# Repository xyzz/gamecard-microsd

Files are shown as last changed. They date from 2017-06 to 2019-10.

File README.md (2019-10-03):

# PS Vita gamecard to microSD adapter

## Software

`driver` contains a kernel module. Add it to taihen's `config.txt` KERNEL section. You can download a precompiled `.skprx` from the [Releases](https://github.com/xyzz/gamecard-microsd/releases) section.

Your microSD card must have no partition table. exFAT filesystem should be written directly to the device. On Linux, do:

```
mkfs.exfat /dev/sdx # (without a number)
```

On Windows, this works: https://redd.it/6o4gqh / https://redd.it/6o62vx

On Mac this should work (Tested on OSX 10.12):

```
# List your attached storage, find your sd card
sudo DiskUtil list
# If necessary, unmount volume
sudo diskutil unmountdisk /dev/diskn (where n is the number of the mounted sd card)
# Format drive
sudo newfs_exfat -R /dev/diskn  
```

After that, the card still works on both Linux and Windows, however other devices might have some problems.

### Compiling the driver

To compile:

```
cd driver
mkdir build && cd build
cmake ..
make
```

## Hardware

`board` contains Autodesk EAGLE schematics and board files. **Note: last revision still untested.**

The pcb has to be 1mm thick. This means I only tested 1mm thick PCBs and found them to work fine. I don't know if other thicknesses work.

Note how the pcb has a hole in place of microsd socket. You need to flip the socket and mount it into the hole .



The socket should look like that. You can buy these from aliexpress for about $0.1-0.2/piece. Check out [issue 2](https://github.com/xyzz/gamecard-microsd/issues/2) for a buying guide.

There's no case for the adapter. Make sure to cover testpoints with some tape to prevent shorts. (v3.0 of the design has no test pads so you do not have to insulate anything). You also will have to use tweezers to remove adapter from PS Vita. Don't grab the adapter by the socket or you risk damaging it.

The adapter does not use Vita gamecard push-pull mechanism. If you feel a spring while inserting it, this means you are inserting it wrong.

If you accidentally short contacts, the Vita will power off. However, in my testing, this does not seem to cause any permanent damage.

Once you insert the adapter, you can replace microSD without taking the adapter out.

## Version history

### v3.0

* Reduced gamecard pads total width by 0.2mm.
* Removed testpads.
* Removed unused INS pad on the microSD socket side.
* Changed routing to reduce number of VIAs and the probability of electrons falling out of the board.

This design is not tested yet.

### v2.0

* Reduced gamecard pads total width by 1.0mm.
* Removed fourth microsd socket leg.

This design is not tested by me yet, but other people confirmed it works.

### v1.0

Original design.

## Alternative designs

You can find some alternative designs here:

* https://github.com/Gadorach/SD2VITA
* https://www.elotrolado.net/hilo_proyecto-hardmod-para-poner-un-lector-de-micro-sd-en-la-psvita_2229693 (Spanish)

(Send a pr if you want to be included here)

## License

Code inside the `driver` directory is licensed under GPLv3 or later.

Contents of the `board` directory are licensed under [CC0](https://creativecommons.org/publicdomain/zero/1.0/).

## Special thanks to

* @motoharu-gosuto for their work on gamecard RE
* @TheOfficialFlow for providing original version of the usbmc plugin

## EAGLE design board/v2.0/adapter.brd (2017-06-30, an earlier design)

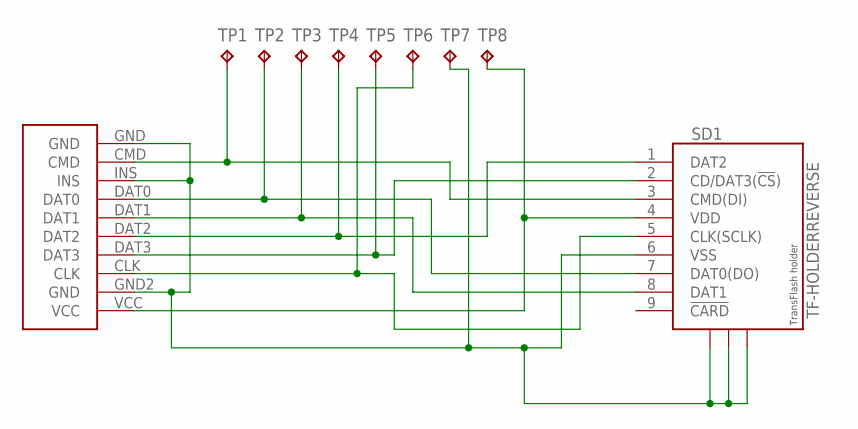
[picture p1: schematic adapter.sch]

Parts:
SD1: TF-HOLDERREVERSE; TF-PULL-REVERSE
TP1, TP2, TP3, TP4, TP5, TP6, TP7, TP8: TPTP20R; TP20R
U$1: CONNECTOR

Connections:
GND: SD1.6 (VSS), SD1.S1, SD1.S2, SD1.S3, TP7.TP, U$1.GND, U$1.GND2 (GND), U$1.INS
unnamed: SD1.4 (VDD), TP8.TP, U$1.VCC
unnamed: SD1.3 (CMD(DI)), TP1.TP, U$1.CMD
unnamed: SD1.7 (DAT0(DO)), TP2.TP, U$1.DAT0
unnamed: SD1.8 (DAT1), TP3.TP, U$1.DAT1
unnamed: SD1.1 (DAT2), TP4.TP, U$1.DAT2
unnamed: SD1.2 (CD/DAT3(!CS!)), TP5.TP, U$1.DAT3
unnamed: SD1.5 (CLK(SCLK)), TP6.TP, U$1.CLK

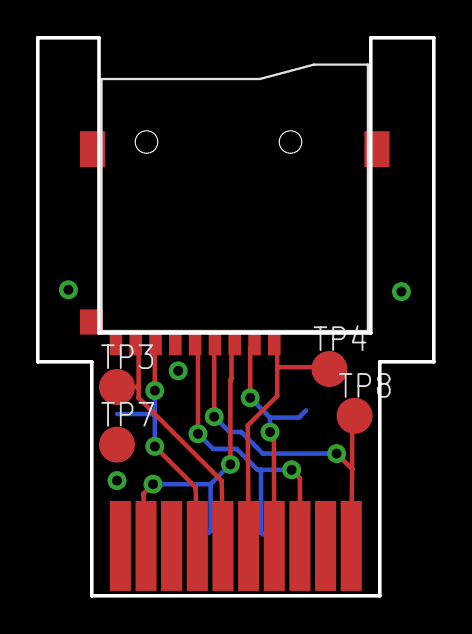
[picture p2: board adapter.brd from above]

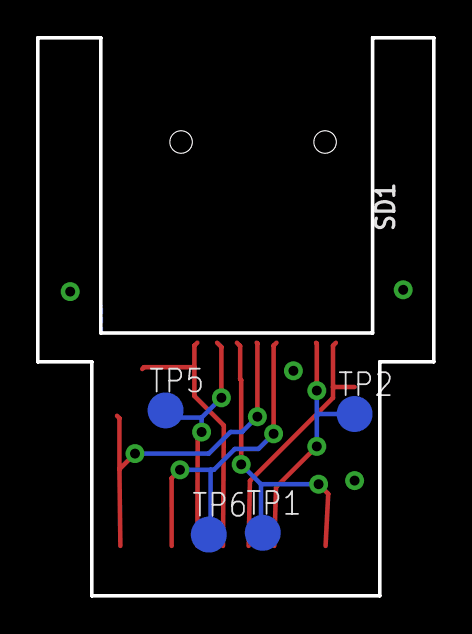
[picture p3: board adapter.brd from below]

Board: 2 copper layers, 22.0 x 31.0 mm, 10 parts (4 on the bottom side), 8 nets.

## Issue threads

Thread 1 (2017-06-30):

Which coating?

devnoname120, 2017-06-30:
xyz: FR4 proto: 2 layers / 5x5cm (2.2x3.1cm) / 1.0mm / HASL / 1oz / Blue / Protopack ±10
basically all default settings except 1mm

xyzz, 2017-07-01:
anything works, just get the default/cheapest one

Closed 2017-07-01.

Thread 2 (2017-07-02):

Sd Connector

DavisDev, 2017-07-02:
Hello Xyzz!,
What is the sd connector model?
Maybe some "serial number" component?
Greetings.

xyzz, 2017-07-02:
I don't know the model number/name. Here's the purchasing guide though.

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

DavisDev, 2017-07-02:
Thanks for answering!
And thanks for all your hard work!

CrazyMaggot, 2017-07-06:
Good afternoon!
Will this work?
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

https://www.chipdip.ru/product0/8492206932

xyzz, 2017-07-06:
I think it should work.

Closed 2017-07-02.

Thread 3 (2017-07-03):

Gerber format

mikadoryu, 2017-07-03:
I'm trying to send a plaque to try this, but the dealer asks me for the circuit in Gerber format (which I try to create but without success from the eagle)

Could you add this format to github?

xyzz, 2017-07-03:
[adapter5.zip](https://github.com/xyzz/gamecard-microsd/files/1119390/adapter5.zip)

Closed 2017-07-03.

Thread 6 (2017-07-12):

Soldering

CrazyMaggot, 2017-07-12:
Good afternoon!
Tell me, do I need to solder the adapter to the card?

xyzz, 2017-07-12:
Yes

CrazyMaggot, 2017-07-12:
Thnx

12 июл. 2017 г. 11:38 пользователь "xyzz" <notifications@github.com>
написал:

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

Closed 2017-07-12.

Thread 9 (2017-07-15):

Error opening board files in Eagle.

a7mag3ddon, 2017-07-15:
Hi,

When i try and open either of the board design files i get this error..

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

xyzz, 2017-07-15:
I double-checked and it is in fact an EAGLE file, which opens fine, so there must be something wrong on your side.

a7mag3ddon, 2017-07-15:
I just downloaded the trial version of AutoDesk Eagle from here > https://www.autodesk.com/products/eagle/free-download

Version 8.2.2 english

What can you suggest i open the files with instead?

a7mag3ddon, 2017-07-15:
What version of eagle are you using ??

xyzz, 2017-07-15:
I use eagle 8.2.1.

Closed 2017-07-15.

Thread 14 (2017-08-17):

Incorrect free memory reported when formatting a high capacity sd with default cluster size

Shinigati, 2017-08-17:
So i'm not entirely sure if this problem is directly related to the plugin or if it's something more focused on the way the vita handles memory cards so i apologise if it's the latter.

but when i formatted my 256gb micro sd card with the default cluster size my vita would always report incorrect free space while windows and all other devices display it just fine but this only happens if the card was filled up by more than about 100gb of data that was tested, and what's more is after a while if i don't do much the free space it claims is still available starts to quickly disappear.

I have flashed zzblank.img, formatted and copied all the files back over twice and the problem still persisted, but finally after talking with a lot of people trying to figure it out i finally found the solution, the free space will only be 100% accurate if when formatting you choose 32kb cluster instead of the default option which in my case was 256kb.

Shinigati, 2017-08-18:
So just a little update on this but some people have reported that one workaround is to format the sd card as Fat32 using the default cluster size which seems to run fine, i have also managed to get 64kb cluster with exFat working as well while 128kb gave the same issue so there definitely appears to be some compatibility issues i just have no idea why.

CelesteBlue-dev, 2017-09-11:
What is your microSD default cluster size ?

Shinigati, 2017-09-11:
I'm now using 64kb and there is no issue at all, before however i believe windows was defaulting it to 256kb, i also made a post on reddit about it and helped a few people by getting them to format using the correct size.

CelesteBlue-dev, 2020-01-11:
Yes, readme should be updated telling that >64kB clusters don't work, and this issue should be closed.

Shinigati, 2020-01-12:
> Yes, readme should be updated telling that >64kB clusters don't work, and this issue should be closed.

I didn't realise this issue was still open but i'm sure everyone knows by now how to correctly format their sd cards.

Closed 2020-01-12.

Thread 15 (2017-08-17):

SD2Vita/gamesd.skprx constantly waking up device

tiduscrying, 2017-08-17:
I've created a few threads over the past couple of days both on [GBATemp](http://gbatemp.net/threads/investigating-a-potential-bug-with-gamesd-skprx.481123/) and on [/r/vitahacks](https://www.reddit.com/r/vitahacks/comments/6twvat/some_really_weird_behavior_with_my_vita/) trying to isolate the issue. It appears that the gamesd.skprx plugin might be causing an issue where the Vita will wake itself up from sleep mode. On my system, the screen will come on completely, the PS button light will flash and then it will go back to sleep after a few seconds. Normally I wouldn't mind this behavior if it happened only once or twice, but it seems to be happening constantly for me and some others (someone reported losing nearly 50% of their battery over night due to constant wake-ups).

I don't have any absolutely concrete evidence aside from the user accounts and my own personal accounts, but I hope that is enough evidence to justify this bug report.

Here are some additional things that I have done to isolate the issue:

- Disable all Henkaku plugins on boot by hold L - issue did not occur
- Disabled just the gamesd.skprx - issue did not occur
- Tried using different SD2Vita adapters - issue occurred
- Tried reinstalling Enso - issue occurred

Again, hopefully this is enough concrete evidence to justify this bug report. This is the only repo I have found for the gamesd.skprx plugin, but I know multiple "versions" of it are floating around. I would assume though that this is where all the versions of the plugin are coming from since I haven't found any other source code anywhere else.

xyzz, 2017-08-17:
Can you try enabling airplane mode?

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

tiduscrying, 2017-08-17:
That actually seems to be working...? Huh. Is there a specific reason for that?

xyzz, 2017-08-17:
I think what happens is that vita wakes up sometimes to check PSN updates, etc (with the screen turned off.)

However, due to my hook executed in resume which pokes gamecard slot to ensure it's mounted, the whole system wakes up. It probably could be fixed by reversing how the system mounts normal game card on wakeup. I don't have time to do that anytime soon, sadly.

tiduscrying, 2017-08-17:
Interesting! Thank you for the info, I should be keeping my system in sleep mode to save battery and hide from Sony anyways! I'll post this to the threads I made so that others can put their systems into sleep mode and avoid the issue for the time being as well.

Thank you!!

tiduscrying, 2017-08-17:
Edit: Well, it seems that I was not paying attention long enough... Just after posting the information to the threads, someone commented saying that their system has been waking itself up but has been in airplane mode the entire time. Literally just as I was about to reply, I witnessed it happen to my own system as well. So I guess airplane mode doesn't eliminate the issue completely?

xyzz, 2017-08-17:
I see, that's unfortunate. You can test the theory however by disabling `suspend_callback`. If it does not work, then I'm not sure what could cause that. If it does work, that's great, microsd won't be mounted after wakeup so a different way to activate it would be needed (right now it simulates removal and reinsertion of game card).

Duckbuster, 2017-08-23:
>(right now it simulates removal and reinsertion of game card)
Is that why it takes a bit longer to load when you open the lockscreen?
(after you swipe it, there's a loading circle thing for me)

slickrasta, 2017-09-26:
I'm having the same issue on my Vita 1000. Airplane mode doesn't seem to help. How would I go about disabling suspend_callback to test that?

slickrasta, 2017-09-26:
Not sure if this is helpful info I do use VitaBright and NoLED plugins and pretty much solely use my Vita to play PS1 games via Adrenaline v6.

SeraphSephiroth, 2017-12-09:
Any update on a fix for this?

devingDev, 2018-03-17:
Not from xyz , does not seem like he can continue working on this so we have to figure it out ourselves.

xyzz, 2018-07-21:
I've tried fixing the issue, please try the attached build and let me know if your vita still wakes up randomly.

[gamesd.zip](https://github.com/xyzz/gamecard-microsd/files/2215779/gamesd.zip)

xyzz, 2018-07-21:
It seems people are still experiencing the issue so I've made another build with a different fix, try it out.

[gamesd.zip](https://github.com/xyzz/gamecard-microsd/files/2216421/gamesd.zip)

xyzz, 2018-07-21:
Okay, here's the third build for testing

[gamesd.zip](https://github.com/xyzz/gamecard-microsd/files/2216608/gamesd.zip)

JuanD817, 2018-07-23:
At 46 minutes, no wakeups at the moment and led doesn't take time to light up

JuanD817, 2018-07-23:
More than an hour in standby and the wakeup issue seems to be fixed :D, i guess third time is the charm, the only problem i see left is that the led turns on at random but i think thats the vitas issue, not the plugin

JuanD817, 2018-07-23:
@CelesteBlue-dev already tried your latest update a couple of weeks ago, it still has random wakeups every couple of minutes, if it got fixed that would be awesome but for now im sticking with this plugin

I commented more than a week ago about the issue here: https://github.com/CelesteBlue-dev/PSVita-StorageMgr/issues/7

CelesteBlue-dev, 2018-07-23:
@JuanD817 on which FW are you ? Is WIFI enabled ? Do you have enso ?
When you were trying StorageMgr, was the LED blinking often in suspend mode ?
Does the LED blink too in third build ?

JuanD817, 2018-07-23:
-FW 3.68
-Wifi is enabled
-I dont have enso
-yes, just the same as when i didnt have my vita with h-encore
-Yes, it still blinks

JuanD817, 2018-07-23:
They both blink the same in suspend mode, but when i use StorageMgr 2.1 after the blinks the LED stays on and my vita wakes up

JuanD817, 2018-07-24:
No problem, glad i could help

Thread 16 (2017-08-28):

sdcard.skprx driver does not play well with usbmc.skprx

hypergreatthing, 2017-08-28:
long story short, i'd like to load yifan's 3g usb device along side the sd2vita card.
The current driver doesn't seem to play nice.  Whichever i call out in config first wins.
Is there anyway to add support for both at the same time?

CelesteBlue-dev, 2017-08-28:
I am developping a plugin that resolves this issue.
It's working.
I'm going to release it in some days.

DieKatzchen, 2017-10-12:
Any progress on this? I'm interested as well, as long as I can choose mount point (since I obviously can't have them both on ux0).

tokyobusridas, 2018-07-27:
Ever get that one put together xyzz? Thanks for everything

CelesteBlue-dev, 2020-01-11:
Here it is lol:
https://github.com/CelesteBlue-dev/PSVita-StorageMgr

CelesteBlue-dev, 2020-01-11:
> I am developping a plugin that resolves this issue.
> It's working.
> I'm going to release it in some days.

Here it is lol:
https://github.com/CelesteBlue-dev/PSVita-StorageMgr

burtman316, 2020-01-11:
You are amazing thanks!
     On Saturday, January 11, 2020, 7:44:21 AM MST, CelesteBlue-dev <notifications@github.com> wrote:

Here it is lol:
https://github.com/CelesteBlue-dev/PSVita-StorageMgr

—
You are receiving this because you are subscribed to this thread.
Reply to this email directly, view it on GitHub, or unsubscribe.

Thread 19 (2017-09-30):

Use Vita memory and sd2vita together

masoudr, 2017-09-30:
Hi,
Is there a proper way to use vita memory card and sd2vita simultaneously? I mean using apps in memory card and sd2vita.
Thanks.

TheRadziu, 2017-10-02:
there are custom gamesd plugins for that. One mounts memory card to uma0 and sd to ux0, the other does it the other way around. check wololo for links to those.

masoudr, 2017-10-02:
Is this make me use apps in both partitions at the same time or I should reboot each time for accessing apps in these partitions?

TheRadziu, 2017-10-03:
You can move apps between partitions with other homebrew app, but IDK if they will work or not (especially nonpdrm). Homebrew apps do work from another partitions, since I checked it myself.

masoudr, 2017-10-03:
Thanks.
If I understand it right you mean that using sd2vita itself with higher capacity is a better option rather than keep it with vita memory. My concern is performance problems with sd2vita, does it have any negative advantage over original vita memory card?

windsurfer1122, 2017-12-12:
Hi John, there are already pull requests available from August 2017 for this topic.
Would also like to see that xyzz incorporates them into his master branch as v2.0.

I use my SD2Vita as uma0 via an "inoffical" build from [Modshiah](https://www.youtube.com/watch?v=vsdbdcAnH4Y).

masoudr, 2017-12-13:
@windsurfer1122 Thanks. I already test that but the problem is it can only be used for some data types and you cant load the vita games from that directory. I'm waiting for a possibility to use both partitions for my vita games.

windsurfer1122, 2017-12-13:
@masoudr Vita games only work from ux0, that's a firmware issue (AFAIK from the many threads I read).
uma0 works fine for most HomeBrew software including Adrenaline.
I do no see a way how the driver could change the firmware to make Vita games work from uma0.

CelesteBlue-dev, 2020-01-11:
You can try https://github.com/CelesteBlue-dev/PSVita-StorageMgr.

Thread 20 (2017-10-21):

Control over mount points

JohnVeness, 2017-10-21:
Many thanks for the driver code.

As you know, others have modified it to mount the gamecardsd as ux0, and even to mount the genuine Vita memory card as uma0 at the same time.

I _was_ going to ask you if you could make those modifications "official" and have alternative driver binaries available to download from your github page, rather than from random untrusted sites.

But then I wondered whether a single binary driver could read a config file at startup to change its behaviour, i.e. the mount points?

E.g. (and I don't know if this is possible) but maybe "pseudo command line arguments" can be passed via tai/config.txt? Or maybe the driver could read its own config file?

Thank you for reading.

windsurfer1122, 2017-12-12:
Hi John, there are already pull requests available from August 2017 for these topics.
Would also like to see that xyzz incorporates them into his master branch as v2.0

JohnVeness, 2017-12-12:
Ah yes, I hadn't noticed those PRs. In that case, this issue can be closed as dupes of the PRs.

JohnVeness, 2018-03-08:
I haven't tried it but it looks like this idea is implemented in https://github.com/CelesteBlue-dev/PSVita-StorageMgr so I'll close this.

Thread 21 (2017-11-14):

Reverting to Vita MC if no SD card inserted

VgaCich, 2017-11-14:
Mount original Vita MC as ux0: if no SD card inserted.

stuermera, 2018-07-08:
Has this been fixed with the 1.3 release of gamesd? :) Thx

xyzz, 2018-07-08:
No

KupoAuster, 2018-08-02:
Not yet fixed.
And here I was thinking it was a good option.

CelesteBlue-dev, 2018-08-23:
https://github.com/CelesteBlue-dev/PSVita-StorageMgr does that.

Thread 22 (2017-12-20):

Permission Issue? App exits

mazh-dini, 2017-12-20:
Using SD2Vita (without a ps memory card) can cause certain apps not to function properly e.g. moonlight. App constantly returns to game menu when a setting is changed and saved (pressing o when done) or when attempting to type an ip since the configuration files in ux0:data/moonlight are not being created/changed when the app is launched.

Could this be a permission issue of some sort since if I didn't have the SD2Vita then the PS Memory card would be mounted as ux0 and the app would work?

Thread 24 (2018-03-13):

Couple of problems on 3.65

superduperdrew12345, 2018-03-13:
On the newest version compatible with 3.65 enso the memory card is no longer mounted to Uma0. Vitanshell still recognizes it as there and in the previous version it worked as expected. Additionally, I'm having trouble installing nonpdrm games on the sd adapter. When I refresh the livearea it says 0 refreshed but if I move the same files to my sd and then comment out gamesd from config.txt then it installs properly on the memory card. Existing nonpdrm games work still so it seems to be a problem with gamesd not allowing the new folder to be picked up.

xyzz, 2018-03-13:
The memory card was never mounted to uma0 with this plugin. I've no idea about nonpdrm I don't use it, try asking its author.

Closed 2018-03-13.

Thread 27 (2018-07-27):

SD2VITA mounted as uma0 instead (alternate version)

itsminht, 2018-07-27:
Is it possible for each update to this plugin, you also release an alternate version in which the sd2vita card is mounted as uma0 instead of ux0? This would be extremely helpful for the few that use this plugin the other way around.

Avrution, 2018-07-27:
Seconded.  I'd love to have the wakeup fix working, but need to mount as uma0.

xPandamon, 2018-07-27:
Yep, i'm up for that. The sporadic wakeups on storagemgr are super annoying. This one: https://github.com/Ninoh-FOX/gamecard-microsd-uma0/releases doesn't seem to be working properly.

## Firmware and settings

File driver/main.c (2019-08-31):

/*
	gamecard-microsd
	Copyright 2017-2018, xyz

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
	You should have received a copy of the GNU General Public License
	along with this program.  If not, see <http://www.gnu.org/licenses/>.
*/

/*
	This software contains code derived from VitaShell.
	Included below is the license header from VitaShell.
*/

/*
	VitaShell
	Copyright (C) 2015-2017, TheFloW

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
	You should have received a copy of the GNU General Public License
	along with this program.  If not, see <http://www.gnu.org/licenses/>.
*/

#include <psp2kern/kernel/cpu.h>
#include <psp2kern/kernel/modulemgr.h>
#include <psp2kern/kernel/sysmem.h>
#include <psp2kern/io/fcntl.h>
#include <psp2kern/kernel/threadmgr.h>

#include <stdio.h>
#include <string.h>

#include <taihen.h>

#define MOUNT_POINT_ID 0x800

int module_get_offset(SceUID pid, SceUID modid, int segidx, size_t offset, uintptr_t *addr);

typedef struct {
	const char *dev;
	const char *dev2;
	const char *blkdev;
	const char *blkdev2;
	int id;
} SceIoDevice;

typedef struct {
	int id;
	const char *dev_unix;
	int unk;
	int dev_major;
	int dev_minor;
	const char *dev_filesystem;
	int unk2;
	SceIoDevice *dev;
	int unk3;
	SceIoDevice *dev2;
	int unk4;
	int unk5;
	int unk6;
	int unk7;
} SceIoMountPoint;

static SceIoDevice uma_ux0_dev = { "ux0:", "exfatux0", "sdstor0:gcd-lp-ign-entire", "sdstor0:gcd-lp-ign-entire", MOUNT_POINT_ID };

static SceIoMountPoint *(* sceIoFindMountPoint)(int id) = NULL;

static SceIoDevice *ori_dev = NULL, *ori_dev2 = NULL;

static void io_remount(int id) {
	ksceIoUmount(id, 0, 0, 0);
	ksceIoUmount(id, 1, 0, 0);
	ksceIoMount(id, NULL, 0, 0, 0, 0);
}

int shellKernelIsUx0Redirected() {
	SceIoMountPoint *mount = sceIoFindMountPoint(MOUNT_POINT_ID);
	if (!mount) {
		return -1;
	}

	if (mount->dev == &uma_ux0_dev && mount->dev2 == &uma_ux0_dev) {
		return 1;
	}

	return 0;
}

int shellKernelRedirectUx0() {
	SceIoMountPoint *mount = sceIoFindMountPoint(MOUNT_POINT_ID);
	if (!mount) {
		return -1;
	}

	if (mount->dev != &uma_ux0_dev && mount->dev2 != &uma_ux0_dev) {
		ori_dev = mount->dev;
		ori_dev2 = mount->dev2;
	}

	mount->dev = &uma_ux0_dev;
	mount->dev2 = &uma_ux0_dev;

	return 0;
}

int shellKernelUnredirectUx0() {
	SceIoMountPoint *mount = sceIoFindMountPoint(MOUNT_POINT_ID);
	if (!mount) {
		return -1;
	}

	if (ori_dev && ori_dev2) {
		mount->dev = ori_dev;
		mount->dev2 = ori_dev2;

		ori_dev = NULL;
		ori_dev2 = NULL;
	}

	return 0;
}

// ux0 redirect by theflow
int redirect_ux0() {
	// Get tai module info
	tai_module_info_t info;
	info.size = sizeof(tai_module_info_t);
	if (taiGetModuleInfoForKernel(KERNEL_PID, "SceIofilemgr", &info) < 0)
		return -1;

	// Get important function
	switch (info.module_nid) {
		case 0x9642948C: // 3.60 retail
			module_get_offset(KERNEL_PID, info.modid, 0, 0x138C1, (uintptr_t *)&sceIoFindMountPoint);
			break;

		case 0xA96ACE9D: // 3.65 retail
		case 0x3347A95F: // 3.67 retail
		case 0x90DA33DE: // 3.68 retail
			module_get_offset(KERNEL_PID, info.modid, 0, 0x182F5, (uintptr_t *)&sceIoFindMountPoint);
			break;

		case 0xF16E72C7: // 3.69 retail
		case 0x81A49C2B: // 3.70 retail
		case 0xF2D59083: // 3.71 retail
		case 0x9C16D40A: // 3.72 retail
			module_get_offset(KERNEL_PID, info.modid, 0, 0x18735, (uintptr_t *)&sceIoFindMountPoint);
			break;

		default:
			return -1;
	}

	shellKernelRedirectUx0();
	io_remount(MOUNT_POINT_ID);

	return 0;
}

int poke_gamecard() {
	tai_module_info_t info;
	info.size = sizeof(tai_module_info_t);
	if (taiGetModuleInfoForKernel(KERNEL_PID, "SceSdstor", &info) < 0)
		return -1;

	void *args = 0;
	int (*int_insert)() = 0;
	int (*int_remove)() = 0;

	module_get_offset(KERNEL_PID, info.modid, 0, 0x3BD5, (uintptr_t *)&int_insert);
	module_get_offset(KERNEL_PID, info.modid, 0, 0x3BC9, (uintptr_t *)&int_remove);

	module_get_offset(KERNEL_PID, info.modid, 1, 0x1B20 + 40 * 1, (uintptr_t *)&args);

	int_remove(0, args);
	ksceKernelDelayThread(500 * 1000);
	int_insert(0, args);
	ksceKernelDelayThread(500 * 1000);

	return 0;
}

tai_hook_ref_t hook_get_partition;
tai_hook_ref_t hook_write;
tai_hook_ref_t hook_mediaid;

uint32_t magic = 0x7FFFFFFF;

void *sdstor_mediaid;

void *my_get_partition(const char *name, size_t len) {
	void *ret = TAI_CONTINUE(void*, hook_get_partition, name, len);
	if (!ret && len == 18 && strcmp(name, "gcd-lp-act-mediaid") == 0) {
		return &magic;
	}
	return ret;
}

uint32_t my_write(uint8_t *dev, void *buf, uint32_t sector, uint32_t size) {
	if (dev[36] == 1 && sector == magic) {
		return 0;
	}
	return TAI_CONTINUE(uint32_t, hook_write, dev, buf, sector, size);
}

uint32_t my_mediaid(uint8_t *dev) {
	uint32_t ret = TAI_CONTINUE(uint32_t, hook_mediaid, dev);

	if (dev[36] == 1) {
		memset(dev + 20, 0xFF, 16);
		memset(sdstor_mediaid, 0xFF, 16);

		return magic;
	}
	return ret;
}

// allow SD cards, patch by motoharu
void patch_sdstor() {
	tai_module_info_t sdstor_info;
	sdstor_info.size = sizeof(tai_module_info_t);
	if (taiGetModuleInfoForKernel(KERNEL_PID, "SceSdstor", &sdstor_info) < 0)
		return;

	module_get_offset(KERNEL_PID, sdstor_info.modid, 1, 0x1720, (uintptr_t *) &sdstor_mediaid);

	// patch for proc_initialize_generic_2 - so that sd card type is not ignored
	char zeroCallOnePatch[4] = {0x01, 0x20, 0x00, 0xBF};
	taiInjectDataForKernel(KERNEL_PID, sdstor_info.modid, 0, 0x2498, zeroCallOnePatch, 4); //patch (BLX) to (MOVS R0, #1 ; NOP)
	taiInjectDataForKernel(KERNEL_PID, sdstor_info.modid, 0, 0x2940, zeroCallOnePatch, 4);

	taiHookFunctionOffsetForKernel(KERNEL_PID, &hook_get_partition, sdstor_info.modid, 0, 0x142C, 1, my_get_partition);
	taiHookFunctionOffsetForKernel(KERNEL_PID, &hook_write, sdstor_info.modid, 0, 0x2C58, 1, my_write);
	taiHookFunctionOffsetForKernel(KERNEL_PID, &hook_mediaid, sdstor_info.modid, 0, 0x3D54, 1, my_mediaid);
}

// allow Memory Card remount
void patch_appmgr() {
	tai_module_info_t appmgr_info;
	appmgr_info.size = sizeof(tai_module_info_t);
	if (taiGetModuleInfoForKernel(KERNEL_PID, "SceAppMgr", &appmgr_info) >= 0) {
		uint32_t nop_nop_opcode = 0xBF00BF00;
		switch (appmgr_info.module_nid) {
			case 0xDBB29DB7: // 3.60 retail
			case 0x1C9879D6: // 3.65 retail
				taiInjectDataForKernel(KERNEL_PID, appmgr_info.modid, 0, 0xB338, &nop_nop_opcode, 4);
				taiInjectDataForKernel(KERNEL_PID, appmgr_info.modid, 0, 0xB368, &nop_nop_opcode, 2);
				break;

			case 0x54E2E984: // 3.67 retail
			case 0xC3C538DE: // 3.68 retail
				taiInjectDataForKernel(KERNEL_PID, appmgr_info.modid, 0, 0xB344, &nop_nop_opcode, 4);
				taiInjectDataForKernel(KERNEL_PID, appmgr_info.modid, 0, 0xB374, &nop_nop_opcode, 2);
				break;

			case 0x321E4852: // 3.69 retail
			case 0x700DA0CD: // 3.70 retail
			case 0xF7846B4E: // 3.71 retail
			case 0xA8E80BA8: // 3.72 retail
				taiInjectDataForKernel(KERNEL_PID, appmgr_info.modid, 0, 0xB34C, &nop_nop_opcode, 4);
				taiInjectDataForKernel(KERNEL_PID, appmgr_info.modid, 0, 0xB37C, &nop_nop_opcode, 2);
				break;
		}
	}
}

void _start() __attribute__ ((weak, alias("module_start")));
int module_start(SceSize args, void *argp) {
	patch_sdstor();
	patch_appmgr();
	poke_gamecard();
	redirect_ux0();

	return SCE_KERNEL_START_SUCCESS;
}

int module_stop(SceSize args, void *argp) {
	return SCE_KERNEL_STOP_SUCCESS;
}

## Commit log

2017-06-30 Add board and readme
    [adapter.brd, adapter.sch]
2017-07-19 Add v3.0
    [adapter.brd, adapter.sch]

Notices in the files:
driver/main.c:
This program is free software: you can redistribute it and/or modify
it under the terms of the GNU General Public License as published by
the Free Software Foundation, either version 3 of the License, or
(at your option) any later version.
